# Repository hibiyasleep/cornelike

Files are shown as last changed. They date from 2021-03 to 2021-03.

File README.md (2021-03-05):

# Cornel

yet another [Crkbd](https://github.com/foostan/crkbd) clone, but with 5 rows.

---

<details>
<summary> Disclaimer </summary>

 ignore this if you're brave enough, like, if you know what Kailh Choc is, then
you are safe.

>  THIS PROJECT IS CURRENTLY WORK IN PROGRESS, NOTHING IS CLEAR, EVERY SPECIFICA-
> TION and/or DIMENSIONS and/or FEATURES and EVERYTHING MIGHT BE ABLE TO CHANGED
> WITHOUT ANY NOTICE. THIS MIGHT NOT FIT WITH YOUR LASER-ETCHED PLATE. THIS MIGHT
> DOES NOT FIT INTO YOUR $400 ALUMINUM CNC-ANODIZED CORNE CASE. YOUR CR2 BATTERY
> MIGHT BE BLOWN (SURE, I ALSO HAVE THIS RISK IN THIS CASE)
>
>  SO ANYWAY, I, HIBIYA INEMURI, DO NOT HOLD ANY TYPE OF RESPONSIBILITY IN ANY
> CASE.

</details>

## About

 According to [Crkbd](https://github.com/foostan/crkbd), the Corne keyboard is:

>  The Corne keyboard is a split keyboard with 3x6 column staggered keys and 3
> thumb keys, based on Helix. Crkbd stands for Corne Keyboard.

 Corne**l** is basically a clone of Corne keyboard, but with

* **Kailh Choc Switches** but keeping cherry pitch (19mm) for V2 keycaps.
* **Number Row**: to provide easy transition to 40% layout.
  can be removed later if no longer required. (irreversible)
* **Bluetooth MCU Support**: Cornel provides battery board (discharge only)
  that fits onto MCU cover, might be able to power [BLE Micro Pro](https://github.com/sekigon-gonnoc/BLE-Micro-Pro/), etc.
* **Low Profile**: Cornel might do any attempt to reduce thickness of keyboard.
  (TBD)

## Progress

* [ ] PCB
  * [x] Choc (revision: 1)
  * [ ] Cherry
* [ ] Plate
  * [ ] Upper (with acrylic and countersink holes)
  * [ ] Lower
* [ ] Software
  * [x] Arduino Demo (TBA)
  * [ ] QMK support
* [ ] Compability
  * [ ] Classic Pro Micro
  * [ ] [BLE Pro Micro](https://github.com/sekigon-gonnoc/BLE-Micro-Pro)
    * [ ] [LPME-IO](https://github.com/sekigon-gonnoc/LPME-IO)...?
  * [ ] [nice!nano](https://docs.nicekeyboards.com/)
  * [ ] TBA
* [ ] Problems
  * [ ] Detachability of Number row
  * [ ] removing LED Signal Skip jumper (by reordering LEDs)
* [ ] Photos

## Photos

> **WORK IN PROGRESS**

* First prototype (revision 0), with lubed 35g Burnt Orange.
  overall picture of revision 0

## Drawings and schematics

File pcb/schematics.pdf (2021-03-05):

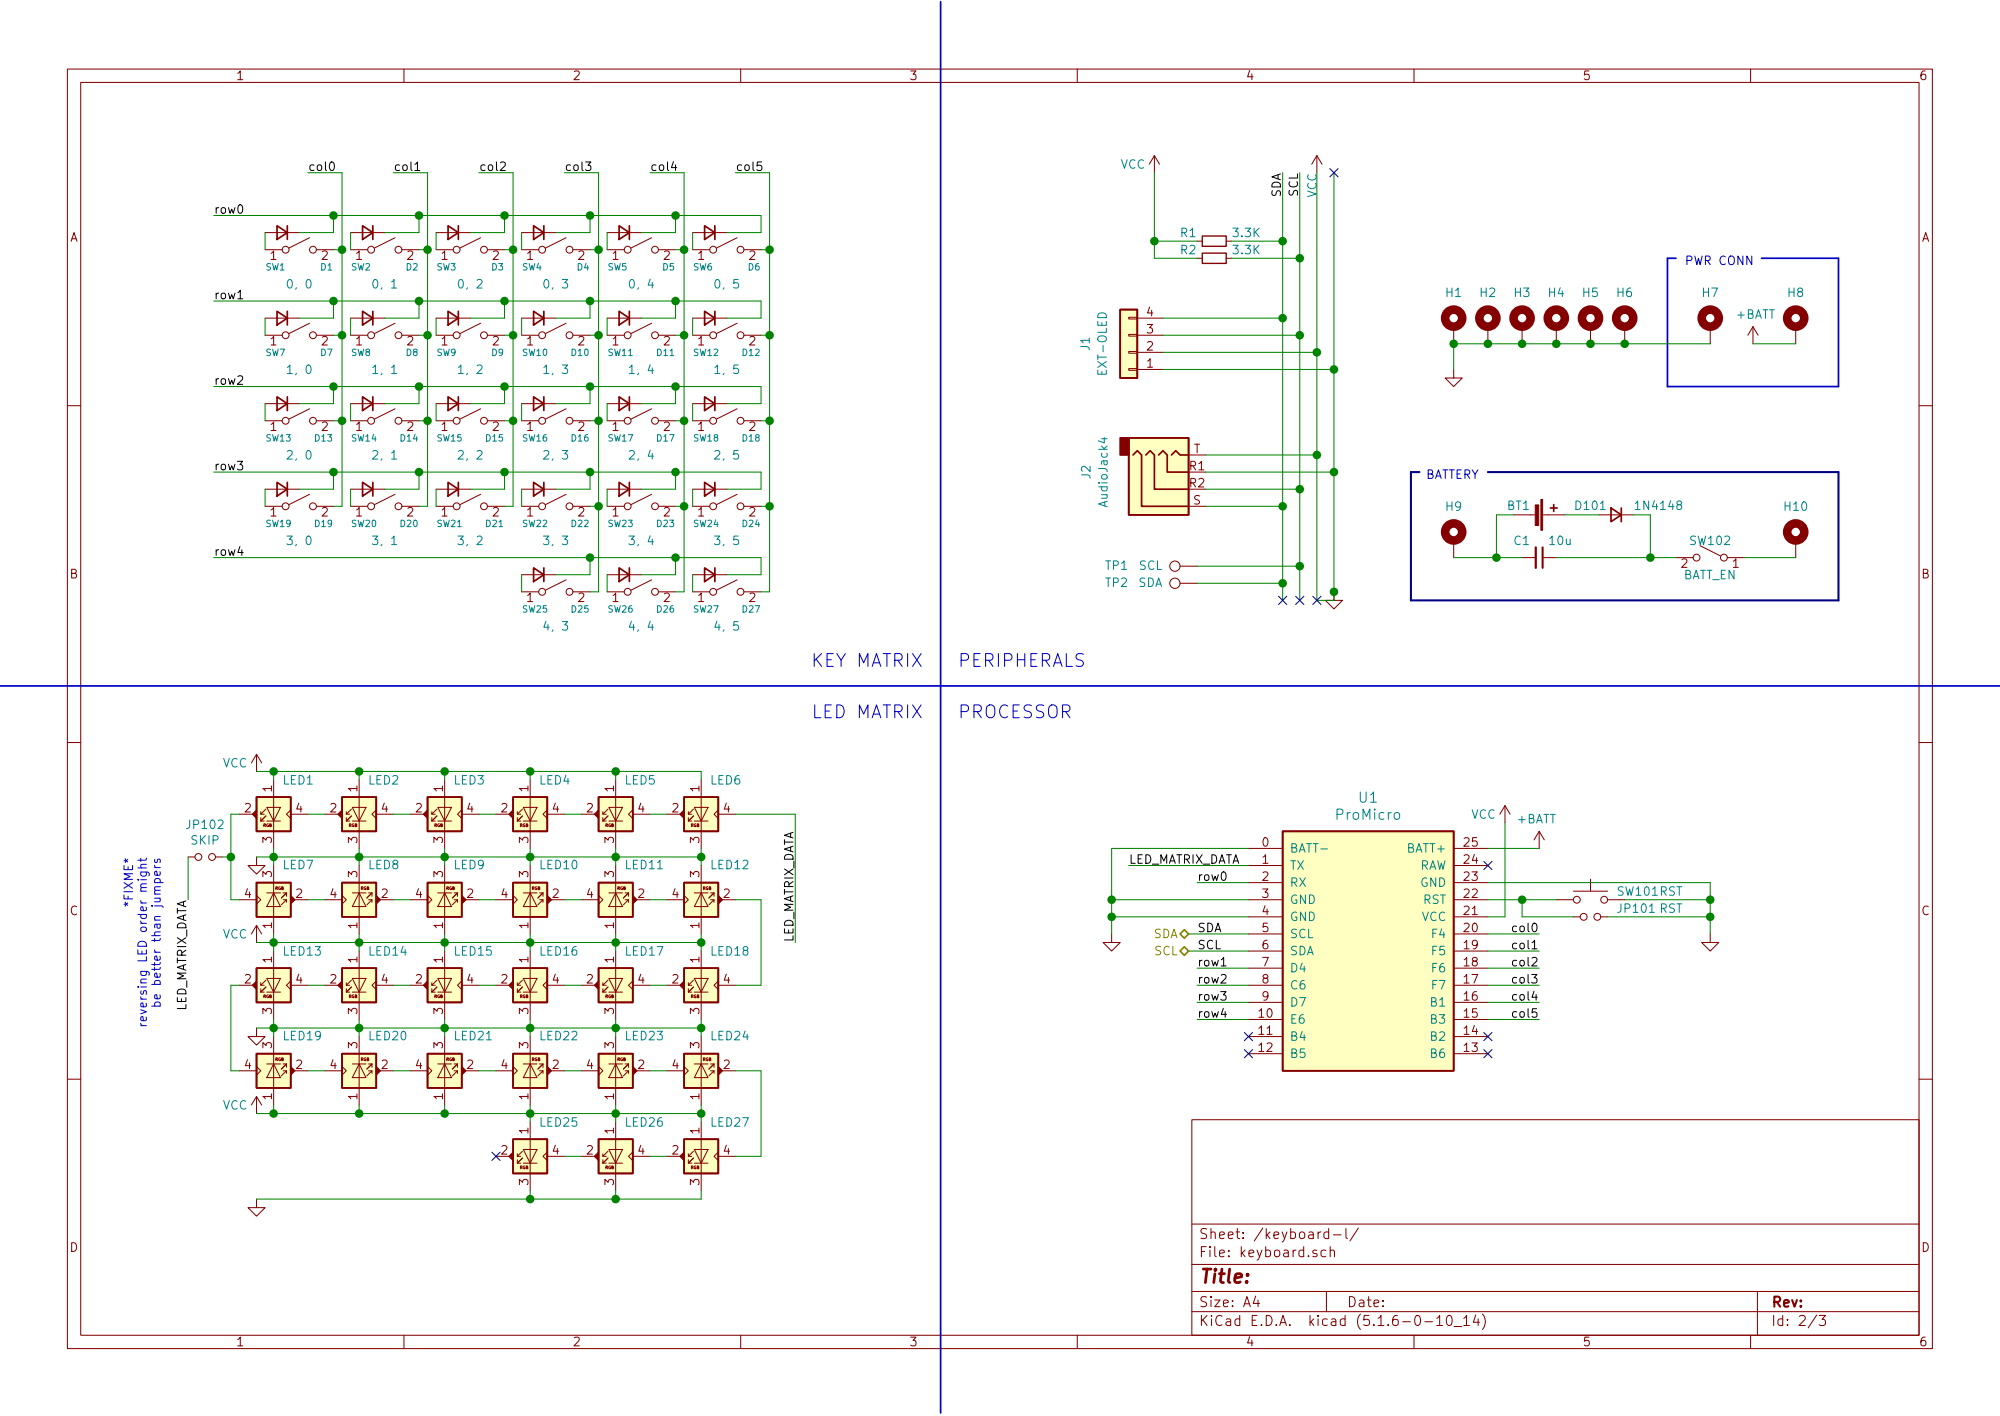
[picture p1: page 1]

BATTERY *FIXME* reversing LED order might be better than jumpers

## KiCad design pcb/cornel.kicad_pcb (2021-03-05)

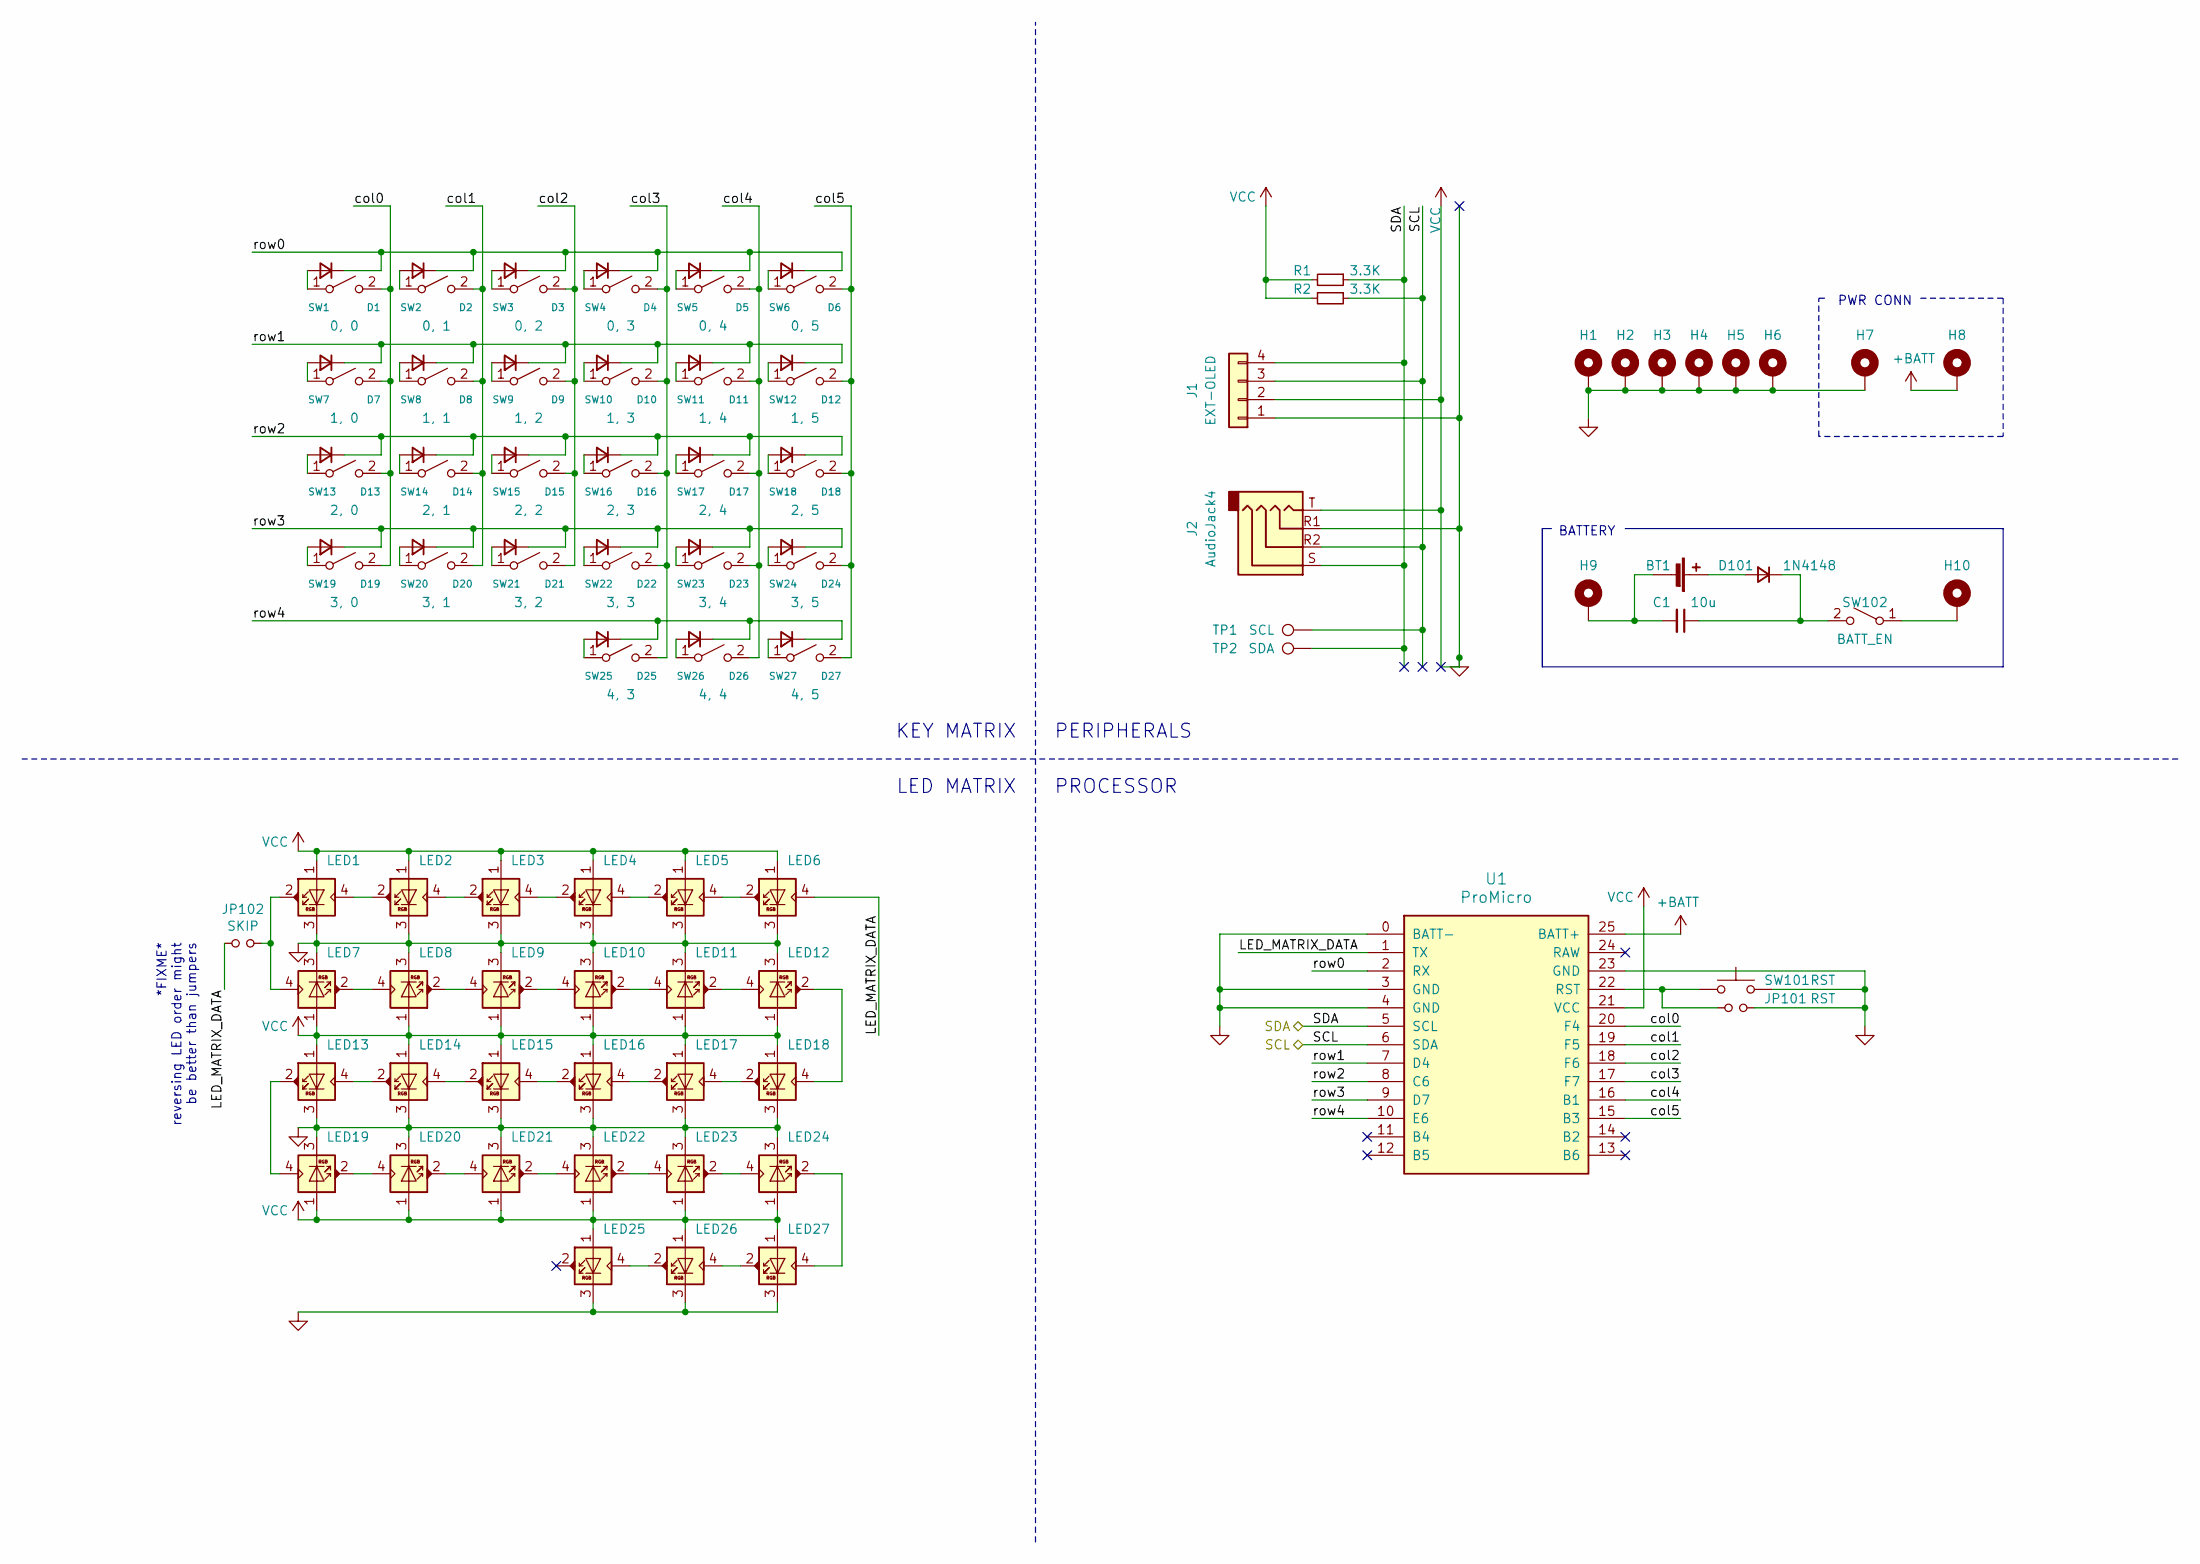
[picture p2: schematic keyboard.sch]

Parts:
BT1: CR1632; keystone-1010-mid-mount-cr2
C1: 10u; C_1206_3216Metric
D1, D2, D3, D4, D5, D6, D7, D8, D9, D10, D11, D12, D13, D14, D15, D16, D17, D18, D19, D20, D21, D22, D23, D24, D25, D26, D27, D101: 1N4148; D_1206_3216Metric
H1, H2, H3, H4, H5, H6: MountingHole_Pad; MountingHole_4.1mm_M2-Pillar_Pad
H7, H8, H9, H10: MountingHole_Pad; MountingHole_2.2mm_Via
J1: EXT-OLED; PinHeader_1x04_P2.54mm_Vertical
J2: AudioJack4; Jack_3.5mm_PJ320A_Horizontal
JP101: RST; SolderJumper-2_P1.3mm_Open_Pad1.0x1.5mm
JP102: SKIP; SolderJumper-2_P1.3mm_Open_Pad1.0x1.5mm
LED1, LED2, LED3, LED4, LED5, LED6, LED7, LED8, LED9, LED10, LED11, LED12, LED13, LED14, LED15, LED16, LED17, LED18, LED19, LED20, LED21, LED22, LED23, LED24, LED25, LED26, LED27: SK6812MINI; SK6812MINI-E_InsidePCB_singleside
R1, R2: 3.3K; R_1206_3216Metric
SW1: 0, 0; kailh-pcb-socket-choc-singleside
SW2: 0, 1; kailh-pcb-socket-choc-singleside
SW3: 0, 2; kailh-pcb-socket-choc-singleside
SW4: 0, 3; kailh-pcb-socket-choc-singleside
SW5: 0, 4; kailh-pcb-socket-choc-singleside
SW6: 0, 5; kailh-pcb-socket-choc-singleside
SW7: 1, 0; kailh-pcb-socket-choc-singleside
SW8: 1, 1; kailh-pcb-socket-choc-singleside
SW9: 1, 2; kailh-pcb-socket-choc-singleside
SW10: 1, 3; kailh-pcb-socket-choc-singleside
SW11: 1, 4; kailh-pcb-socket-choc-singleside
SW12: 1, 5; kailh-pcb-socket-choc-singleside
SW13: 2, 0; kailh-pcb-socket-choc-singleside
SW14: 2, 1; kailh-pcb-socket-choc-singleside
SW15: 2, 2; kailh-pcb-socket-choc-singleside
SW16: 2, 3; kailh-pcb-socket-choc-singleside
SW17: 2, 4; kailh-pcb-socket-choc-singleside
SW18: 2, 5; kailh-pcb-socket-choc-singleside
SW19: 3, 0; kailh-pcb-socket-choc-singleside
SW20: 3, 1; kailh-pcb-socket-choc-singleside
SW21: 3, 2; kailh-pcb-socket-choc-singleside
SW22: 3, 3; kailh-pcb-socket-choc-singleside
SW23: 3, 4; kailh-pcb-socket-choc-singleside
SW24: 3, 5; kailh-pcb-socket-choc-singleside
SW25: 4, 3; kailh-pcb-socket-choc-singleside
SW26: 4, 4; kailh-pcb-socket-choc-singleside
SW27: 4, 5; kailh-pcb-socket-choc-singleside
SW101: RST; SW_Push_SPST_NO_Alps_SKRK
SW102: BATT_EN; K3-1296S
TP1: SCL
TP2: SDA
U1: ProMicro; arduino-pro-micro-with-batt

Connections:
+BATT: H8.1, U1.25 (BATT+); also elsewhere on the board
/keyboard-l/LED_MATRIX_DATA: JP102.2, LED6.4 (DIN), U1.1 (TX)
/keyboard-l/SCL: J1.3, J2.R2, R2.1, U1.6 (SDA)
/keyboard-l/SDA: J1.4, J2.S, R1.1, U1.5 (SCL)
/keyboard-l/col0: SW1.2 (B), SW7.2 (B), SW13.2 (B), SW19.2 (B), U1.20 (F4)
/keyboard-l/col1: SW2.2 (B), SW8.2 (B), SW14.2 (B), SW20.2 (B), U1.19 (F5)
/keyboard-l/col2: SW3.2 (B), SW9.2 (B), SW15.2 (B), SW21.2 (B), U1.18 (F6)
/keyboard-l/col3: SW4.2 (B), SW10.2 (B), SW16.2 (B), SW22.2 (B), SW25.2 (B), U1.17 (F7)
/keyboard-l/col4: SW5.2 (B), SW11.2 (B), SW17.2 (B), SW23.2 (B), SW26.2 (B), U1.16 (B1)
/keyboard-l/col5: SW6.2 (B), SW12.2 (B), SW18.2 (B), SW24.2 (B), SW27.2 (B), U1.15 (B3)
/keyboard-l/row0: D1.1 (K), D2.1 (K), D3.1 (K), D4.1 (K), D5.1 (K), D6.1 (K), U1.2 (RX)
/keyboard-l/row1: D7.1 (K), D8.1 (K), D9.1 (K), D10.1 (K), D11.1 (K), D12.1 (K), U1.7 (D4)
/keyboard-l/row2: D13.1 (K), D14.1 (K), D15.1 (K), D16.1 (K), D17.1 (K), D18.1 (K), U1.8 (C6)
/keyboard-l/row3: D19.1 (K), D20.1 (K), D21.1 (K), D22.1 (K), D23.1 (K), D24.1 (K), U1.9 (D7)
/keyboard-l/row4: D25.1 (K), D26.1 (K), D27.1 (K), U1.10 (E6)
unnamed: BT1.1 (+), D101.2 (A)
unnamed: BT1.2 (-), C1.2, H9.1
unnamed: C1.1, D101.1 (K), SW102.2 (B)
unnamed: D1.2 (A), SW1.1 (A)
unnamed: D2.2 (A), SW2.1 (A)
unnamed: D3.2 (A), SW3.1 (A)
unnamed: D4.2 (A), SW4.1 (A)
unnamed: D5.2 (A), SW5.1 (A)
unnamed: D6.2 (A), SW6.1 (A)
unnamed: D7.2 (A), SW7.1 (A)
unnamed: D8.2 (A), SW8.1 (A)
unnamed: D9.2 (A), SW9.1 (A)
unnamed: D10.2 (A), SW10.1 (A)
unnamed: D11.2 (A), SW11.1 (A)
unnamed: D12.2 (A), SW12.1 (A)
unnamed: D13.2 (A), SW13.1 (A)
unnamed: D14.2 (A), SW14.1 (A)
unnamed: D15.2 (A), SW15.1 (A)
unnamed: D16.2 (A), SW16.1 (A)
unnamed: D17.2 (A), SW17.1 (A)
unnamed: D18.2 (A), SW18.1 (A)
unnamed: D19.2 (A), SW19.1 (A)
unnamed: D20.2 (A), SW20.1 (A)
unnamed: D21.2 (A), SW21.1 (A)
unnamed: D22.2 (A), SW22.1 (A)
unnamed: D23.2 (A), SW23.1 (A)
unnamed: D24.2 (A), SW24.1 (A)
unnamed: D25.2 (A), SW25.1 (A)
unnamed: D26.2 (A), SW26.1 (A)
unnamed: D27.2 (A), SW27.1 (A)
unnamed: H10.1, SW102.1 (A)
unnamed: SW101.2, U1.22 (RST)
unnamed: JP102.1, LED1.2 (DOUT), LED7.4 (DIN)
unnamed: LED1.4 (DIN), LED2.2 (DOUT)
unnamed: LED2.4 (DIN), LED3.2 (DOUT)
unnamed: LED3.4 (DIN), LED4.2 (DOUT)
unnamed: LED4.4 (DIN), LED5.2 (DOUT)
unnamed: LED5.4 (DIN), LED6.2 (DOUT)
unnamed: LED7.2 (DOUT), LED8.4 (DIN)
unnamed: LED8.2 (DOUT), LED9.4 (DIN)
unnamed: LED10.2 (DOUT), LED11.4 (DIN)
unnamed: LED9.2 (DOUT), LED10.4 (DIN)
unnamed: LED11.2 (DOUT), LED12.4 (DIN)
unnamed: LED12.2 (DOUT), LED18.4 (DIN)
unnamed: LED13.2 (DOUT), LED19.4 (DIN)
unnamed: LED13.4 (DIN), LED14.2 (DOUT)
unnamed: LED14.4 (DIN), LED15.2 (DOUT)
unnamed: LED15.4 (DIN), LED16.2 (DOUT)
unnamed: LED16.4 (DIN), LED17.2 (DOUT)
unnamed: LED17.4 (DIN), LED18.2 (DOUT)
unnamed: LED19.2 (DOUT), LED20.4 (DIN)
unnamed: LED20.2 (DOUT), LED21.4 (DIN)
unnamed: LED21.2 (DOUT), LED22.4 (DIN)
unnamed: LED22.2 (DOUT), LED23.4 (DIN)
unnamed: LED23.2 (DOUT), LED24.4 (DIN)
unnamed: LED24.2 (DOUT), LED27.4 (DIN)
unnamed: LED25.4 (DIN), LED26.2 (DOUT)
unnamed: LED26.4 (DIN), LED27.2 (DOUT)

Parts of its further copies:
BT2, BT3: CR1632; keystone-1010-mid-mount-cr2
C2: 10u; C_1206_3216Metric
D28, D29, D30, D31, D32, D33, D34, D35, D36, D37, D38, D39, D40, D41, D42, D43, D44, D45, D46, D47, D48, D49, D50, D51, D52, D53, D54, D201: 1N4148; D_1206_3216Metric
H11, H12, H13, H14, H15, H16: MountingHole_Pad; MountingHole_4.1mm_M2-Pillar_Pad
H17, H18, H19, H20: MountingHole_Pad; MountingHole_2.2mm_Via
J3: EXT-OLED; PinHeader_1x04_P2.54mm_Vertical
J4: AudioJack4; Jack_3.5mm_PJ320A_Horizontal
JP201: RST; SolderJumper-2_P1.3mm_Open_Pad1.0x1.5mm
JP202: SKIP; SolderJumper-2_P1.3mm_Open_Pad1.0x1.5mm
LED28, LED29, LED30, LED31, LED32, LED33, LED34, LED35, LED36, LED37, LED38, LED39, LED40, LED41, LED42, LED43, LED44, LED45, LED46, LED47, LED48, LED49, LED50, LED51, LED52, LED53, LED54: SK6812MINI; SK6812MINI-E_InsidePCB_singleside
R3, R4: 3.3K; R_1206_3216Metric
SW28: 0, 0; kailh-pcb-socket-choc-singleside
SW29: 0, 1; kailh-pcb-socket-choc-singleside
SW30: 0, 2; kailh-pcb-socket-choc-singleside
SW31: 0, 3; kailh-pcb-socket-choc-singleside
SW32: 0, 4; kailh-pcb-socket-choc-singleside
SW33: 0, 5; kailh-pcb-socket-choc-singleside
SW34: 1, 0; kailh-pcb-socket-choc-singleside
SW35: 1, 1; kailh-pcb-socket-choc-singleside
SW36: 1, 2; kailh-pcb-socket-choc-singleside
SW37: 1, 3; kailh-pcb-socket-choc-singleside
SW38: 1, 4; kailh-pcb-socket-choc-singleside
SW39: 1, 5; kailh-pcb-socket-choc-singleside
SW40: 2, 0; kailh-pcb-socket-choc-singleside
SW41: 2, 1; kailh-pcb-socket-choc-singleside
SW42: 2, 2; kailh-pcb-socket-choc-singleside
SW43: 2, 3; kailh-pcb-socket-choc-singleside
SW44: 2, 4; kailh-pcb-socket-choc-singleside
SW45: 2, 5; kailh-pcb-socket-choc-singleside
SW46: 3, 0; kailh-pcb-socket-choc-singleside
SW47: 3, 1; kailh-pcb-socket-choc-singleside
SW48: 3, 2; kailh-pcb-socket-choc-singleside
SW49: 3, 3; kailh-pcb-socket-choc-singleside
SW50: 3, 4; kailh-pcb-socket-choc-singleside
SW51: 3, 5; kailh-pcb-socket-choc-singleside
SW52: 4, 3; kailh-pcb-socket-choc-singleside
SW53: 4, 4; kailh-pcb-socket-choc-singleside
SW54: 4, 5; kailh-pcb-socket-choc-singleside
SW201: RST; SW_Push_SPST_NO_Alps_SKRK
SW202: BATT_EN; K3-1296S
TP3: SCL
TP4: SDA
U2: ProMicro; arduino-pro-micro-with-batt

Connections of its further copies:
+BATT: H18.1, U2.25 (BATT+); also elsewhere on the board
/keyboard-r/LED_MATRIX_DATA: JP202.2, LED33.4 (DIN), U2.1 (TX)
/keyboard-r/SCL: J3.3, J4.R2, R4.1, U2.6 (SDA)
/keyboard-r/SDA: J3.4, J4.S, R3.1, U2.5 (SCL)
/keyboard-r/col0: SW28.2 (B), SW34.2 (B), SW40.2 (B), SW46.2 (B), U2.20 (F4)
/keyboard-r/col1: SW29.2 (B), SW35.2 (B), SW41.2 (B), SW47.2 (B), U2.19 (F5)
/keyboard-r/col2: SW30.2 (B), SW36.2 (B), SW42.2 (B), SW48.2 (B), U2.18 (F6)
/keyboard-r/col3: SW31.2 (B), SW37.2 (B), SW43.2 (B), SW49.2 (B), SW52.2 (B), U2.17 (F7)
/keyboard-r/col4: SW32.2 (B), SW38.2 (B), SW44.2 (B), SW50.2 (B), SW53.2 (B), U2.16 (B1)
/keyboard-r/col5: SW33.2 (B), SW39.2 (B), SW45.2 (B), SW51.2 (B), SW54.2 (B), U2.15 (B3)
/keyboard-r/row0: D28.1 (K), D29.1 (K), D30.1 (K), D31.1 (K), D32.1 (K), D33.1 (K), U2.2 (RX)
/keyboard-r/row1: D34.1 (K), D35.1 (K), D36.1 (K), D37.1 (K), D38.1 (K), D39.1 (K), U2.7 (D4)
/keyboard-r/row2: D40.1 (K), D41.1 (K), D42.1 (K), D43.1 (K), D44.1 (K), D45.1 (K), U2.8 (C6)
/keyboard-r/row3: D46.1 (K), D47.1 (K), D48.1 (K), D49.1 (K), D50.1 (K), D51.1 (K), U2.9 (D7)
/keyboard-r/row4: D52.1 (K), D53.1 (K), D54.1 (K), U2.10 (E6)
unnamed: BT2.1 (+), D201.2 (A)
unnamed: BT2.2 (-), C2.2, H19.1
unnamed: C2.1, D201.1 (K), SW202.2 (B)
unnamed: D28.2 (A), SW28.1 (A)
unnamed: D29.2 (A), SW29.1 (A)
unnamed: D30.2 (A), SW30.1 (A)
unnamed: D31.2 (A), SW31.1 (A)
unnamed: D32.2 (A), SW32.1 (A)
unnamed: D33.2 (A), SW33.1 (A)
unnamed: D34.2 (A), SW34.1 (A)
unnamed: D35.2 (A), SW35.1 (A)
unnamed: D36.2 (A), SW36.1 (A)
unnamed: D37.2 (A), SW37.1 (A)
unnamed: D38.2 (A), SW38.1 (A)
unnamed: D39.2 (A), SW39.1 (A)
unnamed: D40.2 (A), SW40.1 (A)
unnamed: D41.2 (A), SW41.1 (A)
unnamed: D42.2 (A), SW42.1 (A)
unnamed: D43.2 (A), SW43.1 (A)
unnamed: D44.2 (A), SW44.1 (A)
unnamed: D45.2 (A), SW45.1 (A)
unnamed: D46.2 (A), SW46.1 (A)
unnamed: D47.2 (A), SW47.1 (A)
unnamed: D48.2 (A), SW48.1 (A)
unnamed: D49.2 (A), SW49.1 (A)
unnamed: D50.2 (A), SW50.1 (A)
unnamed: D51.2 (A), SW51.1 (A)
unnamed: D52.2 (A), SW52.1 (A)
unnamed: D53.2 (A), SW53.1 (A)
unnamed: D54.2 (A), SW54.1 (A)
unnamed: H20.1, SW202.1 (A)
unnamed: SW201.2, U2.22 (RST)
unnamed: JP202.1, LED28.2 (DOUT), LED34.4 (DIN)
unnamed: LED28.4 (DIN), LED29.2 (DOUT)
unnamed: LED29.4 (DIN), LED30.2 (DOUT)
unnamed: LED30.4 (DIN), LED31.2 (DOUT)
unnamed: LED31.4 (DIN), LED32.2 (DOUT)
unnamed: LED32.4 (DIN), LED33.2 (DOUT)
unnamed: LED34.2 (DOUT), LED35.4 (DIN)
unnamed: LED35.2 (DOUT), LED36.4 (DIN)
unnamed: LED36.2 (DOUT), LED37.4 (DIN)
unnamed: LED37.2 (DOUT), LED38.4 (DIN)
unnamed: LED38.2 (DOUT), LED39.4 (DIN)
unnamed: LED39.2 (DOUT), LED45.4 (DIN)
unnamed: LED40.2 (DOUT), LED46.4 (DIN)
unnamed: LED40.4 (DIN), LED41.2 (DOUT)
unnamed: LED41.4 (DIN), LED42.2 (DOUT)
unnamed: LED42.4 (DIN), LED43.2 (DOUT)
unnamed: LED43.4 (DIN), LED44.2 (DOUT)
unnamed: LED44.4 (DIN), LED45.2 (DOUT)
unnamed: LED46.2 (DOUT), LED47.4 (DIN)
unnamed: LED47.2 (DOUT), LED48.4 (DIN)
unnamed: LED48.2 (DOUT), LED49.4 (DIN)
unnamed: LED49.2 (DOUT), LED50.4 (DIN)
unnamed: LED50.2 (DOUT), LED51.4 (DIN)
unnamed: LED51.2 (DOUT), LED54.4 (DIN)
unnamed: LED52.4 (DIN), LED53.2 (DOUT)
unnamed: LED53.4 (DIN), LED54.2 (DOUT)

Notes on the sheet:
*FIXME* reversing LED order might be better than jumpers
BATTERY
PWR CONN
PERIPHERALS
LED MATRIX
PROCESSOR
KEY MATRIX

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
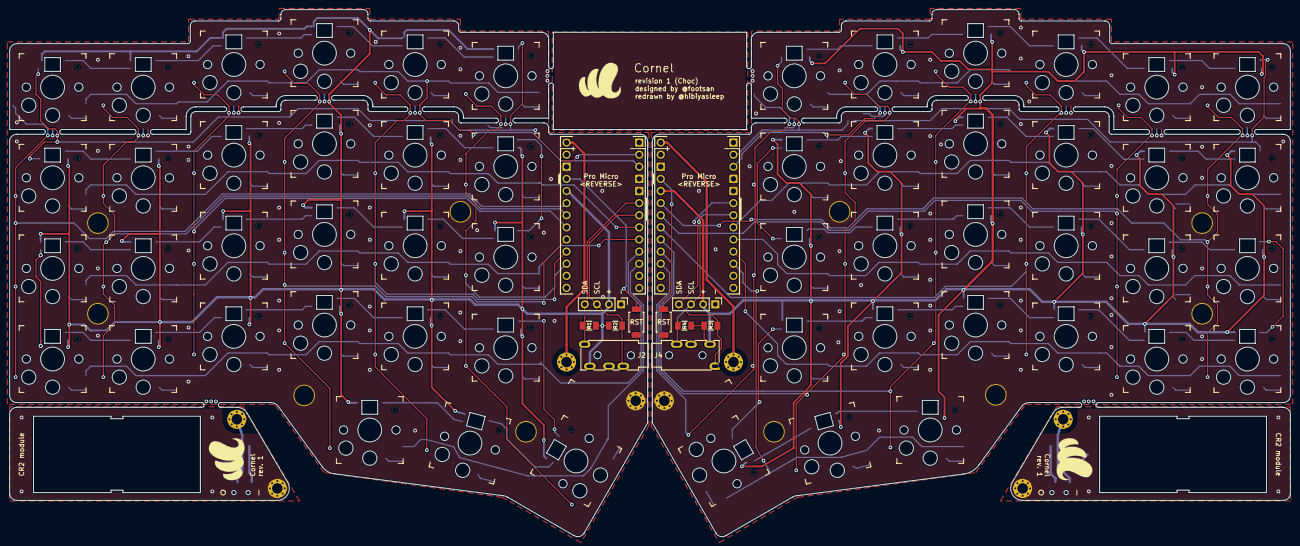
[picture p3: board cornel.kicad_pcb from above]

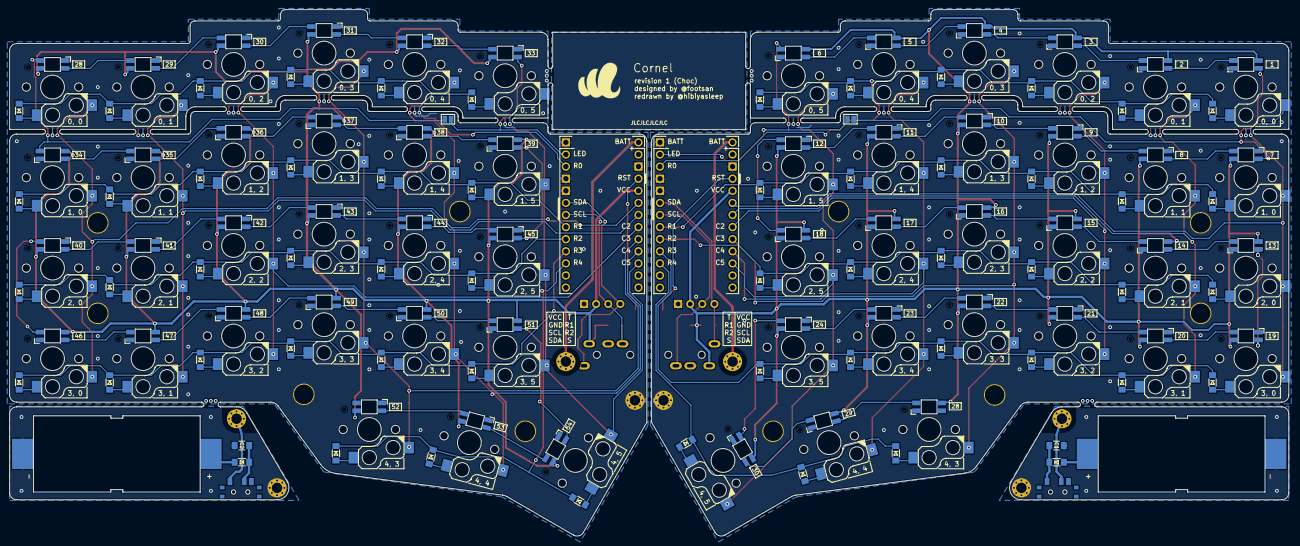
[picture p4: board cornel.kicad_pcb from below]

Board: 2 copper layers, 268.5 x 110.5 mm, 202 parts (66 on the bottom side), 147 nets.

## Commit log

2021-03-05 pcb: initial commit
    [cornel-plate-top.kicad_pcb, cornel.kicad_pcb, cornel.sch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]
2021-03-05 pcb: cleanup & added schematics.pdf
    [cornel.kicad_pcb, keyboard.sch]
2021-03-05 Cornel PCB version r1
